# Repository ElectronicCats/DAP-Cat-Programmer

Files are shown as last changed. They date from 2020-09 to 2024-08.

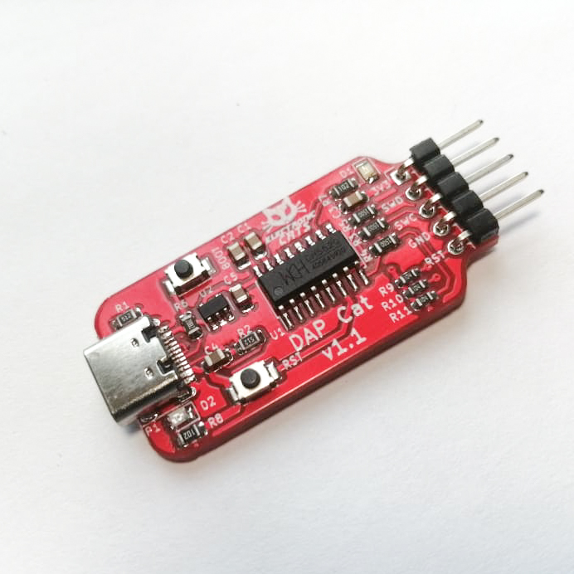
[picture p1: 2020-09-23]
Docs/dap_cat_programmer.jpg

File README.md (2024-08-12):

# CMSIS-DAP Cat Programmer

<a href="https://github.com/ElectronicCats/DAP-Cat-Programmer/wiki">
  <p align="center">
  
    </p>
</a>

<p align=center>
<a href="https://electroniccats.com/store/dapcat/">
  
</a>
<a href="https://github.com/ElectronicCats/DAP-Cat-Programmer/wiki">
  
</a>
</p>

## Description
An Open-Source CMSIS-DAP Debug Probe based on DAPLink. DAP Cat Programmer is a low-cost $5.00 USD debug probe based on the CMSIS-DAP (also known as DAPLink) protocol standard and USB-Serial conversion, and it can realize USB conversion to serial interface. It can be used to program and debug the application software running on Arm Cortex Microcontrollers.

The probe comes with indicator LEDs, a button to reset the target or trigger the firmware update, a reversible USB-C connector, and an easy-to-use 10-pin 2.54mm Header.

## Special Thanks

- [Deqing Sun](https://github.com/DeqingSun)
- CH552 Group in Telegram

## How to contribute 
 Contributions are welcome! 

Please read the document  [**Contribution Manual**](https://github.com/ElectronicCats/electroniccats-cla/blob/main/electroniccats-contribution-manual.md)  which will show you how to contribute your changes to the project.

✨ Thanks to all our [contributors](https://github.com/ElectronicCats/Cat-Sink/graphs/contributors)! ✨

See [**_Electronic Cats CLA_**](https://github.com/ElectronicCats/electroniccats-cla/blob/main/electroniccats-cla.md) for more information.

See the  [**community code of conduct**](https://github.com/ElectronicCats/electroniccats-cla/blob/main/electroniccats-community-code-of-conduct.md) for a vision of the community we want to build and what we expect from it."			

## License
LGPL

Electronic Cats invests time and resources providing this open source design, please support Electronic Cats and open-source hardware by purchasing products from Electronic Cats!

Designed by Electronic Cats.

Firmware released under an GNU LGPL v3.0 license. See the LICENSE file for more information.

Hardware released under an CERN Open Hardware Licence v1.2. See the LICENSE_HARDWARE file for more information.

Electronic Cats is a registered trademark, please do not use if you sell these PCBs.

29 Agu 2020

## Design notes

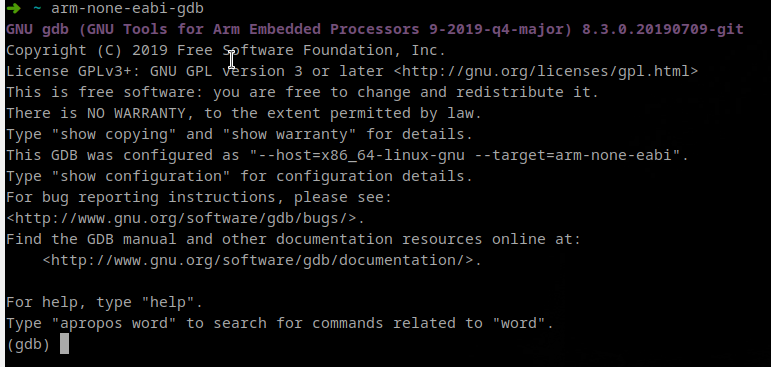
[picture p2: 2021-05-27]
Docs/executingGDB.png

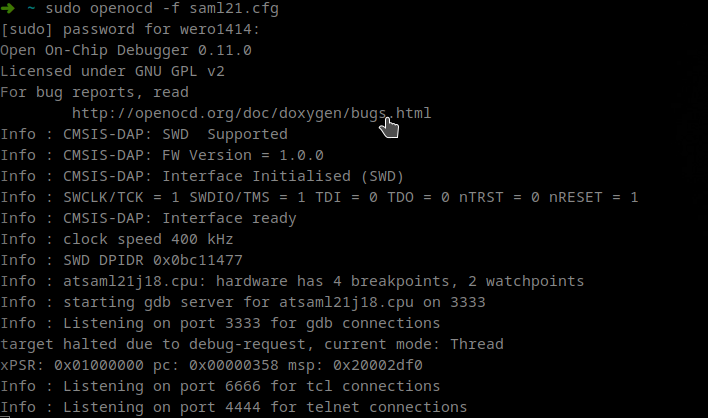
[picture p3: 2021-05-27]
Docs/openOCDRunning.png

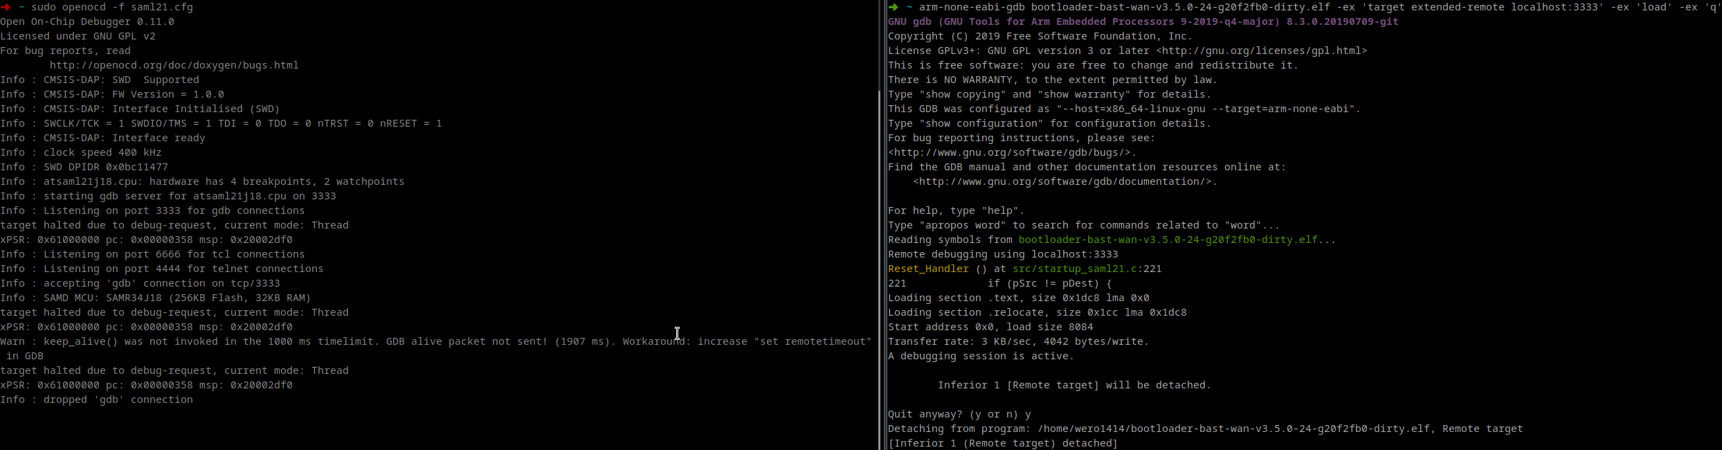
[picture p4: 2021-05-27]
Docs/flashComplete.png

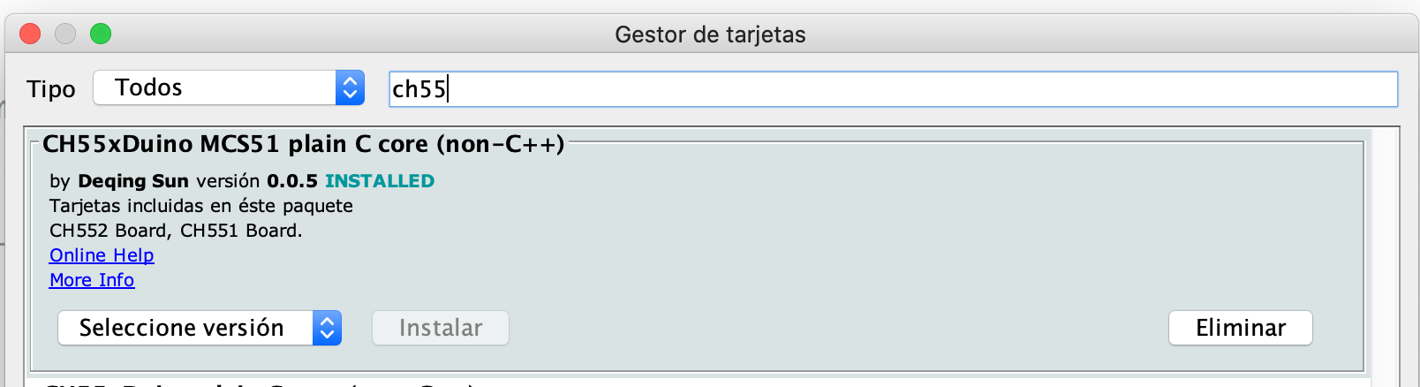
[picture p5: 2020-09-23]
Docs/Board_manager.png

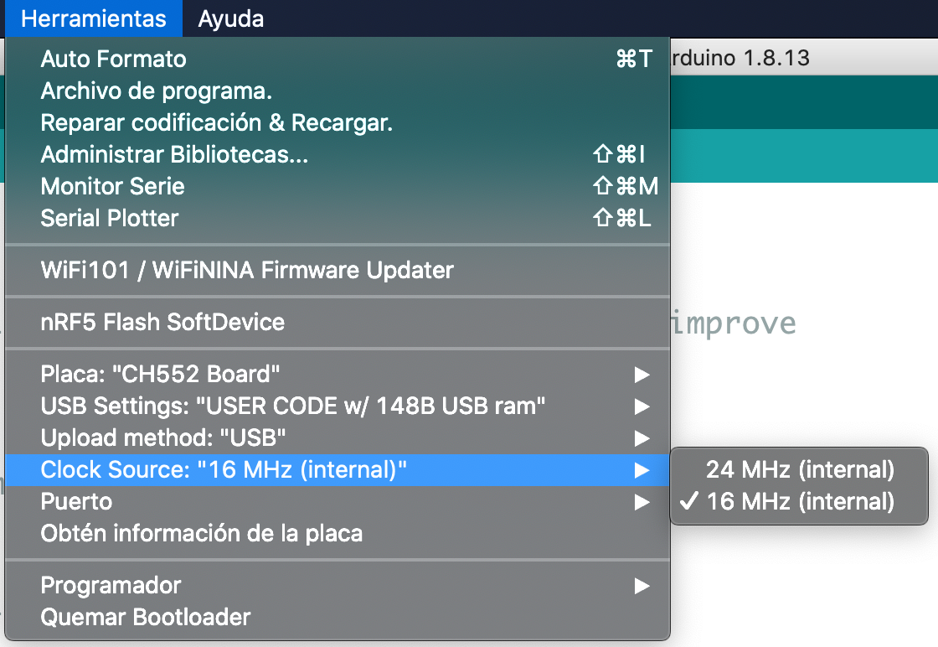
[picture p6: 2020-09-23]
Docs/Settings_IDE.png

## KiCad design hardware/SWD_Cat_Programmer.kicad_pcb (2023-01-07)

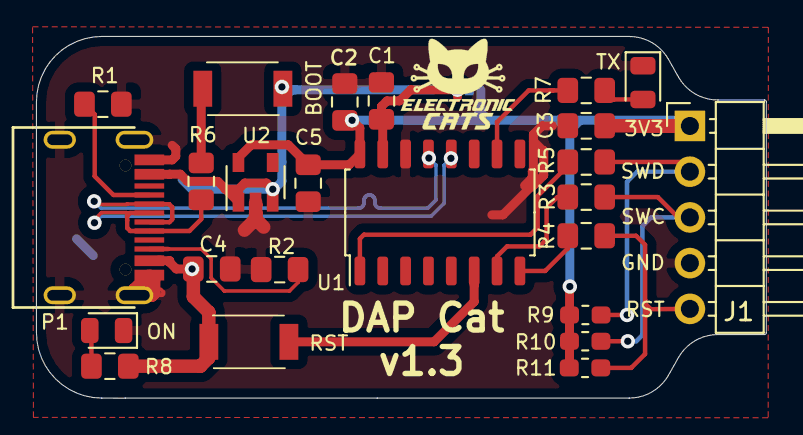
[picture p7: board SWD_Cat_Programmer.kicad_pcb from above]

Board: 2 copper layers, 40.5 x 20.1 mm, 25 parts (1 on the bottom side), 19 nets.

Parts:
BOOT: BOOT; TS1088R02026
C1, C2, C3: 0.1uF; C_0805_2012Metric_Pad1.15x1.40mm_HandSolder
C4, C5: 1uF; C_0805_2012Metric_Pad1.15x1.40mm_HandSolder
J1: DEBUG_OUTPUT; PinHeader_1x05_P2.54mm_Horizontal
JP1: Jumper; SolderJumper-3_P1.3mm_Bridged12_RoundedPad1.0x1.5mm
ON: LED; LED_0805_2012Metric
P1: USB_C_Plug_USB2.0; C393939
R1, R2: 5.1K; R_0805_2012Metric_Pad1.15x1.40mm_HandSolder
R3, R4, R5: 150; R_0805_2012Metric_Pad1.15x1.40mm_HandSolder
R6: 20K; R_0805_2012Metric_Pad1.15x1.40mm_HandSolder
R7, R8: 1K; R_0805_2012Metric_Pad1.15x1.40mm_HandSolder
R9, R10, R11: 70; R_0603_1608Metric_Pad1.05x0.95mm_HandSolder
RST: RST; TS1088R02026
TX: LED; LED_0805_2012Metric
U1: CH552G; SOP-16_4.55x10.3mm_P1.27mm
U2: AP2112K-3.3; SOT-23-5

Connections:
+3V3: C2.1, C3.1, C5.1, J1.1, JP1.1, R9.2, R10.2, R11.2, U1.16, U2.5
+5V: BOOT.1, C4.1, JP1.3, P1.A4, R8.2, RST.1, U2.1, U2.3
/D+: P1.A6, R6.1, U1.12
/D-: P1.A7, U1.13
/LED: R7.2, U1.10
/RESET: J1.5, R4.1, R11.1
/RST: RST.2, U1.6
/SWCLK: J1.3, R3.1, R10.1
/SWDIO: J1.2, R5.1, R9.1
GND: C1.2, C2.2, C3.2, C4.2, C5.2, J1.4, ON.1, P1.A1, P1.S1, R1.1, R2.1, TX.1, U1.14, U2.2
unnamed: C1.1, JP1.2, U1.15
unnamed: R7.1, TX.2
unnamed: ON.2, R8.1
unnamed: P1.A5, R1.2
unnamed: P1.B5, R2.2
unnamed: R3.2, U1.7
unnamed: R4.2, U1.8
unnamed: R5.2, U1.1
unnamed: BOOT.2, R6.2

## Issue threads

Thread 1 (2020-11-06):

Board design questions

wifixcort, 2020-11-06:
Hi.

I have 3 questions about your board design:

1. Why do you use 2 F.Cu and 2 B.Cu Zone outlines instead of just use one for each side?
2.There is a espetial reason for use 0.508 clearance instead a smaller one
3.You make a big loop on 5V or A4 pin in the USB connector, is that really needed, because fisically is the same pin, I think it's not necesary, or I'm wrong?

If you change the rotation of some components it turn out a simplier PCB routing

sabas1080, 2020-11-06:
Hi @wifixcort

1.- An error when designing does not affect anything but we will remove
2.- It is just the design standard we use
3.- double connection is necessary for USB-C

Welcome to contribute if you consider the design can be improved, we look forward to your pullrequest

wifixcort, 2020-11-06:
Could you create a branch named : "develop"

sabas1080, 2020-11-06:
@wifixcort ok for me, send me pullrequest when ready, thanks :D

sabas1080, 2020-11-06:
solution #2

Closed 2020-11-06.

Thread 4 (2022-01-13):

License question

elfmimi, 2022-01-13:
README.md says,
> Firmware released under an GNU AGPL v3.0 license. See the LICENSE file for more information.

[The image](https://raw.githubusercontent.com/ElectronicCats/AjoloteBoard/master/OpenSourceLicense.png) says,
> Software GPL-3.0-or-later

And the LICENSE file says,
> GNU LESSER GENERAL PUBLIC LICENSE Version 2.1

Which is correct?

I believe in this case as ARM originating source files are licensed under Apache-2.0, rest of the firmware code ought to be LGPL .

Could you clarify this and fix the document? (I suppose the image can be just removed.)

sabas1080, 2022-01-18:
corrected, thanks for your notes @elfmimi

elfmimi, 2022-01-19:
Thank you for your quick action. @sabas1080

There is still this line. and it is still confusing.
> Firmware released under an GNU **AGPL** v3.0 license. See the LICENSE file for more information.

sabas1080, 2022-01-19:
corrected

Closed 2022-01-18.

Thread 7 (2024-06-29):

DAPCat not recognized as a CMSIS-DAP device

Daniel9719, 2024-06-29:
**Describe the problem:**
I've bought the DAPCat and tried to make it run under OpenOCD using the cmsis-dap interface but the device does not seem to be recognized as a CMSIS DAP device.

I tried to contact the support team of Electronic Cats ([support1@electroniccats.com](mailto:support1@electroniccats.com)) back on October 5th, 2022 with the subject "DapCat" under my email ([danieldraftsman@gmail.com](mailto:danieldraftsman@gmail.com)) but I didn't get a solution to this problem. I was instructed to reflash my device using the release file CMSIS_DAP.ino.ch552.hex found at  https://github.com/ElectronicCats/DAP-Cat-Programmer/releases using the WCHISPTool and by setting the device on boot mode (which I accomplished by pressing the boot button on the board while I powered on the device). I was successful at flashing the file into the board as you can see below

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

But even after following those steps I haven't been able to have the device recognized as a CMSIS-DAP device.

**Reproduce steps**
First, have the device recognized by the linux environment, you can use the command `lsusb` for this purpose as illustrated below

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

Run the following command under a linux environment (I've specified my environment below)
`sudo openocd -c "gdb_port 50000" -c "tcl_port 50001" -c "telnet_port 50002" -s /home/danielortiz2/OS_Course_Skills/os_core_skills_course -c "debug_level 4" -f /home/vscode/.vscode-server/extensions/marus25.cortex-debug-1.12.1/support/openocd-helpers.tcl -f /interface/cmsis-dap.cfg -c "transport select swd" -f /target/stm32f4x.cfg `

**Expected behavior:**
I'd expect the DAPCat to be recognized as a CMSIS-DAP device

**Screenshots:**
The result that I get from OpenOCD after running the previous  command is the following:

> Open On-Chip Debugger 0.11.0
Licensed under GNU GPL v2
For bug reports, read
        http://openocd.org/doc/doxygen/bugs.html
User : 16 3 options.c:63 configuration_output_handler(): debug_level: 4
User : 17 3 options.c:63 configuration_output_handler():
Debug: 18 3 configuration.c:97 find_file(): found /home/vscode/.vscode-server/extensions/marus25.cortex-debug-1.12.1/support/openocd-helpers.tcl
User : 19 3 options.c:63 configuration_output_handler(): CDLiveWatchSetupUser : 20 3 options.c:63 configuration_output_handler():
Debug: 21 3 configuration.c:97 find_file(): found /usr/bin/../share/openocd/scripts//interface/cmsis-dap.cfg
Debug: 22 4 command.c:146 script_debug(): command - adapter driver cmsis-dap
Debug: 24 4 command.c:146 script_debug(): command - transport select swd
User : 25 4 options.c:63 configuration_output_handler(): swdUser : 26 4 options.c:63 configuration_output_handler():
Debug: 27 4 configuration.c:97 find_file(): found /usr/bin/../share/openocd/scripts//target/stm32f4x.cfg
Debug: 28 4 configuration.c:97 find_file(): found /usr/bin/../share/openocd/scripts/target/swj-dp.tcl
Debug: 29 4 command.c:146 script_debug(): command - transport select
Debug: 30 4 configuration.c:97 find_file(): found /usr/bin/../share/openocd/scripts/mem_helper.tcl
Debug: 31 4 command.c:146 script_debug(): command - add_usage_text mrw address
Debug: 33 4 command.c:1115 help_add_command(): added 'mrw' help text
Debug: 34 5 command.c:146 script_debug(): command - add_help_text mrw Returns value of word in memory.
Debug: 36 5 command.c:1128 help_add_command(): added 'mrw' help text
Debug: 37 5 command.c:146 script_debug(): command - add_usage_text mrh address
Debug: 39 5 command.c:1115 help_add_command(): added 'mrh' help text
Debug: 40 5 command.c:146 script_debug(): command - add_help_text mrh Returns value of halfword in memory.
Debug: 42 5 command.c:1128 help_add_command(): added 'mrh' help text
Debug: 43 5 command.c:146 script_debug(): command - add_usage_text mrb address
Debug: 45 5 command.c:1115 help_add_command(): added 'mrb' help text
Debug: 46 5 command.c:146 script_debug(): command - add_help_text mrb Returns value of byte in memory.
Debug: 48 5 command.c:1128 help_add_command(): added 'mrb' help text
Debug: 49 5 command.c:146 script_debug(): command - add_usage_text mmw address setbits clearbits
Debug: 51 5 command.c:1115 help_add_command(): added 'mmw' help text
Debug: 52 5 command.c:146 script_debug(): command - add_help_text mmw Modify word in memory. new_val = (old_val & ~clearbits) | setbits;
Debug: 54 5 command.c:1128 help_add_command(): added 'mmw' help text
Debug: 55 5 command.c:146 script_debug(): command - transport select
Debug: 56 5 command.c:146 script_debug(): command - transport select
Debug: 57 5 command.c:146 script_debug(): command - transport select
Debug: 58 5 command.c:146 script_debug(): command - swd newdap stm32f4x cpu -irlen 4 -ircapture 0x1 -irmask 0xf -expected-id 0x2ba01477
Debug: 59 5 tcl.c:571 jim_newtap_cmd(): Creating New Tap, Chip: stm32f4x, Tap: cpu, Dotted: stm32f4x.cpu, 8 params
Debug: 60 5 core.c:1484 jtag_tap_init(): Created Tap: stm32f4x.cpu @ abs position 0, irlen 0, capture: 0x0 mask: 0x0
Debug: 61 5 command.c:146 script_debug(): command - dap create stm32f4x.dap -chain-position stm32f4x.cpu
Debug: 62 5 command.c:146 script_debug(): command - transport select
Debug: 63 5 command.c:146 script_debug(): command - target create stm32f4x.cpu cortex_m -endian little -dap stm32f4x.dap
Debug: 64 5 command.c:375 register_command(): command 'rtt' is already registered in '<global>' context
Debug: 65 5 command.c:146 script_debug(): command - stm32f4x.cpu configure -work-area-phys 0x20000000 -work-area-size 0x8000 -work-area-backup 0
Debug: 66 5 target.c:2172 target_free_all_working_areas_restore(): freeing all working areas
Debug: 67 5 target.c:2172 target_free_all_working_areas_restore(): freeing all working areas
Debug: 68 5 target.c:2172 target_free_all_working_areas_restore(): freeing all working areas
Debug: 69 5 command.c:146 script_debug(): command - flash bank stm32f4x.flash stm32f2x 0 0 0 0 stm32f4x.cpu
Debug: 71 6 tcl.c:1319 handle_flash_bank_command(): 'stm32f2x' driver usage field missing
Debug: 72 6 command.c:146 script_debug(): command - flash bank stm32f4x.otp stm32f2x 0x1fff7800 0 0 0 stm32f4x.cpu
Debug: 74 6 command.c:375 register_command(): command 'stm32f2x' is already registered in '<global>' context
Debug: 75 6 command.c:375 register_command(): command 'lock' is already registered in 'stm32f2x' context
Debug: 76 6 command.c:375 register_command(): command 'unlock' is already registered in 'stm32f2x' context
Debug: 77 6 command.c:375 register_command(): command 'mass_erase' is already registered in 'stm32f2x' context
Debug: 78 6 command.c:375 register_command(): command 'options_read' is already registered in 'stm32f2x' context
Debug: 79 6 command.c:375 register_command(): command 'options_write' is already registered in 'stm32f2x' context
Debug: 80 6 command.c:375 register_command(): command 'optcr2_write' is already registered in 'stm32f2x' context
Debug: 81 6 command.c:375 register_command(): command 'otp' is already registered in 'stm32f2x' context
Debug: 82 6 tcl.c:1319 handle_flash_bank_command(): 'stm32f2x' driver usage field missing
Debug: 83 6 command.c:146 script_debug(): command - adapter speed 2000
Debug: 85 6 core.c:1822 jtag_config_khz(): handle jtag khz
Debug: 86 6 core.c:1785 adapter_khz_to_speed(): convert khz to interface specific speed value
Debug: 87 6 core.c:1785 adapter_khz_to_speed(): convert khz to interface specific speed value
Debug: 88 6 command.c:146 script_debug(): command - adapter srst delay 100
Debug: 90 6 command.c:146 script_debug(): command - transport select
Debug: 91 6 command.c:146 script_debug(): command - reset_config srst_nogate
Debug: 93 6 command.c:146 script_debug(): command - transport select
Debug: 94 6 command.c:146 script_debug(): command - cortex_m reset_config sysresetreq
Debug: 96 6 command.c:146 script_debug(): command - stm32f4x.cpu configure -event examine-end
        # Enable debug during low power modes (uses more power)
        # DBGMCU_CR |= DBG_STANDBY | DBG_STOP | DBG_SLEEP
        mmw 0xE0042004 0x00000007 0
        # Stop watchdog counters during halt
        # DBGMCU_APB1_FZ |= DBG_IWDG_STOP | DBG_WWDG_STOP
        mmw 0xE0042008 0x00001800 0
Debug: 97 6 command.c:146 script_debug(): command - stm32f4x.cpu configure -event trace-config
        # Set TRACE_IOEN; TRACE_MODE is set to async; when using sync
        # change this value accordingly to configure trace pins
        # assignment
        mmw 0xE0042004 0x00000020 0
Debug: 98 6 command.c:146 script_debug(): command - stm32f4x.cpu configure -event reset-init
        # Configure PLL to boost clock to HSI x 4 (64 MHz)
        mww 0x40023804 0x08012008   ;# RCC_PLLCFGR 16 Mhz /8 (M) * 128 (N) /4(P)
        mww 0x40023C00 0x00000102   ;# FLASH_ACR = PRFTBE | 2(Latency)
        mmw 0x40023800 0x01000000 0 ;# RCC_CR |= PLLON
        sleep 10                    ;# Wait for PLL to lock
        mmw 0x40023808 0x00001000 0 ;# RCC_CFGR |= RCC_CFGR_PPRE1_DIV2
        mmw 0x40023808 0x00000002 0 ;# RCC_CFGR |= RCC_CFGR_SW_PLL
        # Boost JTAG frequency
        adapter speed 8000
Debug: 99 6 command.c:146 script_debug(): command - stm32f4x.cpu configure -event reset-start
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
Eric286, 2024-07-25:
Hello @Daniel9719

I'm going to try to replicate the problem to see the fastest option to solve it.

Could you try reflashing the device please, follow the same procedure to flash the device using the WCHISPTool and set the device in boot mode.

Have a nice Day!

Eric286, 2024-08-01:
Hello @Daniel9719

Could you tell me how many times you tried to flash the device and if you tried it with another computer?

Have a nice Day!

Daniel9719, 2024-08-03:
Hi Eric, I've just reflashed the device with the WCHISPTool following the same instructions from my first comment and I still have the same issue. Im using the  CMSIS_DAP.ino.ch552.hex file from the release 1.1 although I zee that you have a new version 1.2 without an  CMSIS_DAP.ino.ch552.hex file on it. Could it be possible to get the  CMSIS_DAP.ino.ch552.hex for that version?
So far I've tried reflashing 5 times and still the same messages. Not sure if I'm missing a step or something, specailly because there's no manual with the right procedures to follow

Eric286, 2024-08-07:
[hex file.zip](https://github.com/user-attachments/files/16534191/hex.file.zip)

Hello @Daniel9719

Here I give you the File, if you could record the process when you upload it, if it gives you any errors to verify what else could be happening.

Have a nice Day!

Eric286, 2024-08-13:
Hello @Daniel9719

Was the file helpful to you?

Did you get a different error?

Have a nice Day!

Daniel9719, 2024-08-15:
Hi Eric,

Sorry I don't have a tool to record my screen but I was able to flash the new hex file into the device without any errors but I'm seeing the same error on OpenOCD =/. The only difference I've noticed is the product name being CH55x CMSIS-DAP and having a USB ID 1209:c55d. I've attached the files with the logs I got from OpenOCD, running lsusb and dmseg

[lsusb_Log.txt](https://github.com/user-attachments/files/16620429/lsusb_Log.txt)
[dmesg_Log.txt](https://github.com/user-attachments/files/16620430/dmesg_Log.txt)
[OpenOCD_Log.txt](https://github.com/user-attachments/files/16620431/OpenOCD_Log.txt)

Eric286, 2024-08-19:
Hi @Daniel9719

Please flash the first file (CMSIS_DAP.ino.ch552.hex), and a moment before these lines appear:

Debug: 117 9 cmsis_dap_usb_bulk.c:176 cmsis_dap_usb_open(): enumerating interfaces of 0x1209:0xc550
Debug: 118 9 cmsis_dap_usb_bulk.c:243 cmsis_dap_usb_open(): skipping interface 0, endpoint[0] is not bulk out}

press and hold the boot button

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

Eric286, 2024-08-29:
Hello @Daniel9719,

Due to lack of response we will close this issue now, however, please feel free to reach out to us again in case you have further suggestions, encounter an issue, or you would like to contribute.

Have a nice day!

Support Team.

Closed 2024-08-29.

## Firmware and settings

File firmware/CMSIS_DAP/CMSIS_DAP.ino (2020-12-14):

/*
  CMSIS_DAP

  Modified form ljbfly's implementation, working but a lot to improve
  RST   -> P30
  SWCLK -> P31
  SWDIO -> P32
  These pins works in OC mode with pull-up resistor (70K). Should be safe to connect 3.3V part.

  created 2020
  by Deqing Sun for use with CH55xduino

  This example code is in the public domain.

*/

//For windows user, if you ever played with other HID device with the same PID C55D
//You may need to uninstall the previous driver completely        


#ifndef USER_USB_RAM
#error "This example needs to be compiled with a USER USB setting"
#endif

#include "src/CMSIS_DAPusb/DAP.h"


extern volatile __xdata uint8_t USBByteCountEP1;


void setup() {
  USBInit();
}

void loop() {
  uint8_t dapSendLength = 0;
  if (USBByteCountEP1) {
    dapSendLength = DAP_Thread();
    USBByteCountEP1 = 0;

    UEP1_CTRL = UEP1_CTRL & ~ MASK_UEP_R_RES | UEP_R_RES_ACK; //enable receive

    UEP1_T_LEN = 64;
    UEP1_CTRL = UEP1_CTRL & ~ MASK_UEP_T_RES | UEP_T_RES_ACK; //enable send
  }
}

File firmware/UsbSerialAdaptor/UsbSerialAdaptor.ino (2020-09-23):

/*
  UsbSerialAdaptor

  A simple example turns CH552 to a serial adaptor, 
  relaying data between USB serial and Serial0.

  Baudrate of Serial0 is determined by USB serial's rate.

  created 2020
  by Deqing Sun for use with CH55xduino

  This example code is in the public domain.

*/

extern __xdata uint8_t LineCoding[]; //lineCoding of CDC is located in this array
__xdata uint32_t oldBaudRate = 9600;

void setup() {
  Serial0_begin(9600);
}

void loop() {
  while (USBSerial_available()) {
    char serialChar = USBSerial_read();
    Serial0_write(serialChar);
  }
  while (Serial0_available()) {
    char serialChar = Serial0_read();
    USBSerial_write(serialChar);
  }

  __xdata uint32_t currentBaudRate = *((__xdata uint32_t *)LineCoding); //both linecoding and sdcc are little-endian

  if (oldBaudRate != currentBaudRate) {
    oldBaudRate = currentBaudRate;
    Serial0_begin(currentBaudRate);
  }

}

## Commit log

2020-08-02 Init Schematic
    [SWD_Cat_Programmer.kicad_pcb, SWD_Cat_Programmer.sch]
2020-08-04 Bom and footprints added
    [BOM_Cat_Programmer.xlsx, SWD_Cat_Programmer.sch]
2020-08-05 capacitors modified
    [BOM_Cat_Programmer.xlsx, SWD_Cat_Programmer.sch]
2020-08-06 added logos EC
    [SWD_Cat_Programmer.kicad_pcb]
2020-08-06 labels added
    [SWD_Cat_Programmer.kicad_pcb]
2020-08-06 modifed design
    [SWD_Cat_Programmer.kicad_pcb]
2020-08-06 buttons changed
    [SWD_Cat_Programmer.sch]
2020-08-07 Pull up Resistors Update
    [SWD_Cat_Programmer.kicad_pcb, SWD_Cat_Programmer.sch]
2020-08-07 jumper voltage
    [SWD_Cat_Programmer.sch]
2020-08-09 update label
    [SWD_Cat_Programmer.kicad_pcb]
2020-08-30 change path hardware
    [BOM_Cat_Programmer.xlsx, SWD_Cat_Programmer.kicad_pcb, SWD_Cat_Programmer.sch]
2020-09-01 pin output changed
    [BOM_Cat_Programmer.xlsx, SWD_Cat_Programmer.kicad_pcb, SWD_Cat_Programmer.sch]
2020-09-01 fix path for Arduino
    [CMSIS_DAP.ino, DAP.h]
2020-09-02 v1.1 align
    [SWD_Cat_Programmer.kicad_pcb, SWD_Cat_Programmer.sch]
2020-09-04 update some data
    [BOM_Cat_Programmer.xlsx, SWD_Cat_Programmer.sch]
2020-09-23 Add Drivers Windows
2020-09-27 Update labels for Serial Adapter
    [SWD_Cat_Programmer.kicad_pcb, SWD_Cat_Programmer.sch]
2020-10-13 abierto open hardware month edition
    [SWD_Cat_Programmer.kicad_pcb]
2020-11-06 Cupper Zones Fixed
    [SWD_Cat_Programmer.kicad_pcb]
2020-11-06 enhanced routing
    [SWD_Cat_Programmer.kicad_pcb]
2020-11-06 Fix labels, added contribution name Ricardo Mena
    [SWD_Cat_Programmer.kicad_pcb]
2020-12-14 Fix USB and DAP for PyOCD and Keil
    [CMSIS_DAP.ino, DAP.h]
2020-12-15 fix multiple command issue
    [DAP.h]
2021-05-27 add cfg scripts for openOCD
    [nrf52.cfg, saml21.cfg]
2023-01-07 Revert "enhanced routing"
    This reverts commit 42d6ad708d969779b1270b3bd74ecf01ee581fea.
    [SWD_Cat_Programmer.kicad_pcb, SWD_Cat_Programmer.kicad_sch]
2023-12-20 Update README.md
    Changes:
    1.- Adding pictures of the device to the general information section and wiki section.
    2.- Adding a button and the link to the store
    3.- Adding a button and the link to the wiki
    4.- Removing information about technical features, drivers and manuals to the wiki
2023-12-21 Update README.md
    Changes in the button to the store
2023-12-22 Update README.md
    Updates on device pictures (no version visible)
2024-08-12 fix:Update README.md
    To update device's cost and resize the main picture
2024-08-12 fix:Update README.md
    To resize the device's picture
